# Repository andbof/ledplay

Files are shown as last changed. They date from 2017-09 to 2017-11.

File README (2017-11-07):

Ledplay is a small project aimed as a childrens toy. It uses a Cortex M0+
(Kinetis KE04, MKE04Z8VWJ4) to light button leds in binary order, waiting for
them to be pressed. When a complete number has been pressed, it progresses to
the next, until all have been exhausted. It then resets from one.

Copyright (C) 2016 Andreas Bofjäll <andreas@gazonk.org>, see LICENSE for
licensing details.

DESIGN RATIONALE

  Power efficiency was paramount, but I still wanted to retain programmability
  and flexibility for future use cases. The whole circuit is running at around
  130 uA when no leds are lit, giving it a runtime of about 1 to 1.5 years on
  two double AA batteries. There are no current limiting resistors for the leds
  and the led dc-dc drives them using constant voltage, but they won't be lit
  long enough for their resistance drop to become a problem.

  The led dc-dc is a SEPIC because originally, the leds would be driven with a
  lower voltage, but they turned out to be too dim.

SCHEMATICS AND PCB

  Schematic and PCB are made in Kicad. The PCB is a four layer board (mostly
  because I wanted to play with multilayer boards).

COMPILING

  Enter the src directory and run "make". You need a standard gcc arm toolchain
  (arm-none-eabi-*) installed, but nothing else. Ledplay does not use CMSIS.

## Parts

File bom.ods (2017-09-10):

 | Producer | Model | Note | Distributor | Art. no | Price (each) | Needed | Ordered | Sum | Buy | Board names
Battery holder | Keystone | 2463 |  | Farnell | 1702631 | 11.00 kr | 1 |  | 11.00 kr
Capacitor | Walsin | 1206X226K160CT | 22 uF, 16V, X5R, 1206 | Farnell | 2497154 | 3.08 kr | 3 |  | 9.24 kr |  | C1 C12 C17
Capacitor | TDK | C2012X7R1C105K125AA | 1 uF, 16V, X7R, 0805 | Farnell | 2346937 | 0.52 kr | 4 |  | 2.07 kr |  | C8 C10 C13 C16
Capacitor | TDK | C3216X7R1C106M160AC | 10 uF, 16V, X7R, 1206 | Farnell | 2309039 | 1.60 kr | 3 |  | 4.80 kr |  | C3 C18 C20
Capacitor | Kemet | C0603C180J5GACTU | 18 pF, C0G, 0603 | Farnell | 1414620 | 0.22 kr | 2 |  | 0.44 kr |  | C5 C6
Capacitor | Murata | GCM1885C1H221JA16D | 220 pF, C0G, 0603 | Farnell | 2494190 | 0.10 kr | 1 |  | 0.10 kr |  | C15
Capacitor | Multicomp | MC0603B104K250CT | 100 nF, X7R, 0603 | Farnell | 2310560 | 0.02 kr | 7 |  | 0.14 kr | No | C2 C4 C7 C9 C11 C14 C19
Connector | Molex | 22-23-2021 | 1x2, battery | Farnell | 1462926 | 0.74 kr | 1 |  | 0.74 kr |  | P1
Connector | TE / AMP | 281695-5 | 5 pins, keyed | Farnell | 1205986 | 2.95 kr | 4 |  | 11.80 kr |  | P2 P3 P4 P5
Connector | TE / AMP | 281838-5 | 5 pins, keyed | Farnell | 429600 | 1.75 kr | 4 |  | 7.00 kr
Connector | Wurth | 61900211621 | 1x2, battery | Farnell | 1841370 | 1.20 kr | 1 |  | 1.20 kr
CPU | NXP | MKE04Z8VWJ4 |  | Farnell | 2409293 | 8.77 kr | 1 |  | 8.77 kr |  | U1
Crystal | TXC | 9C-14.7456MEEJ-T | 14.7456 MHz | Farnell | 1842290 | 5.60 kr | 1 |  | 5.60 kr |  | Y1
DC/DC | Linear | LT1610 |  | Farnell | 2252763 | 39.53 kr | 1 |  | 39.53 kr |  | U4
DC/DC | Linear | LTC3429 |  | Farnell | 1663903 | 39.35 kr | 1 |  | 39.35 kr |  | U5
Header |  |  | 1x3, through hole |  |  |  | 1 |  | 0.00 kr | No | J1
Header |  |  | 1x2, through hole |  |  |  | 2 |  | 0.00 kr | No | JP1 P6
Header |  |  | 2x10, 1x27 mm, th | Farnell | 1022308 | 21.70 kr | 1 |  | 21.70 kr |  | J2
Inductance | Bourns | SRF0703-220M | Dual, 22 uH | Farnell | 1852820 | 8.65 kr | 1 |  | 8.65 kr |  | L1
Inductance | Murata | LQH43PN6R8M26L | 6.8 uH, 1812 | Farnell | 2219286 | 2.13 kr | 2 |  | 4.26 kr |  | L2
LED | Multicomp | 703-0087 | Green, 2.1 V, 572 nm | Farnell | 2112096 | 1.80 kr | 4 |  | 7.20 kr
Mosfet | NXP | NXP-BSS138BK |  | Farnell | 2053833 | 0.32 kr | 4 |  | 1.29 kr |  | Q1 Q2 Q3 Q4
Resistor | Panasonic | ERJ3RED2203V | 220 kohm, 0,5%, 0603 | Farnell | 2380163 | 0.59 kr | 1 |  | 0.59 kr |  | R28
Resistor | Vishay | CRCW0603604KFKEA | 604 kohm, 0603 | Farnell | 2138581 | 0.33 kr | 1 |  | 0.33 kr |  | R33
Resistor | Panasonic | ERJ3EKF7873V | 787 kohm, 0603 | Farnell | 2303313 | 0.10 kr | 1 |  | 0.10 kr |  | R30
Resistor | Panasonic | ERJ3RED5603V | 560 kohm, 0,5%, 0603 | Farnell | 2380240 | 0.59 kr | 1 |  | 0.59 kr |  | R29
Resistor | Panasonic | ERJ3RED1004V | 1 Mohm, 0.5%, 0603 | Farnell | 2380099 | 0.56 kr | 1 |  | 0.56 kr |  | R31
Resistor | Yageo | RC0603FR-07330RL | 330 ohm, 0603 | Farnell | 9238425 | 0.16 kr | 1 |  | 0.16 kr |  | R6
Resistor | Multicomp | MC0063W060311K | 1 kohm, 0603 | Farnell | 2130855 | 0.00 kr | 8 |  | 0.04 kr | No | R7 R8 R9 R10 R17 R18 R19 R20
Resistor | Multicomp | MC0063W0603110K | 10 kohm, 0603 | Farnell | 2130939 | 0.02 kr | 3 |  | 0.05 kr | No | R2 R3 R4
Resistor | Multicomp | MCMR06X2002FTL | 20 kohm, 0603 | Farnell | 2073421 | 0.09 kr | 1 |  | 0.09 kr |  | R32
Resistor | Multicomp | MCWR06X1003FTL | 100 kohm, 0603 | Farnell | 2447226RL | 0.01 kr | 12 |  | 0.16 kr | No | R11 R12 R13 R14 R15 R16 R21 R22 R23 R24 R25 R26
Schmitt NAND | TI | CD4093BM96 | Quad | Farnell | 2407129 | 1.78 kr | 2 |  | 3.56 kr |  | U2 U3
Schottky diode | ON | MBR0520LT3G |  | Farnell | 2533224 | 0.70 kr | 2 |  | 1.40 kr |  | D1 D2
Switch | C&K | KSEM31G LFS | 50 mA, SMD | Farnell | 2435310 | 2.55 kr | 1 |  | 2.55 kr |  | SW1
SUM |  |  |  |  |  |  | 85 | 0 | 195.05 kr

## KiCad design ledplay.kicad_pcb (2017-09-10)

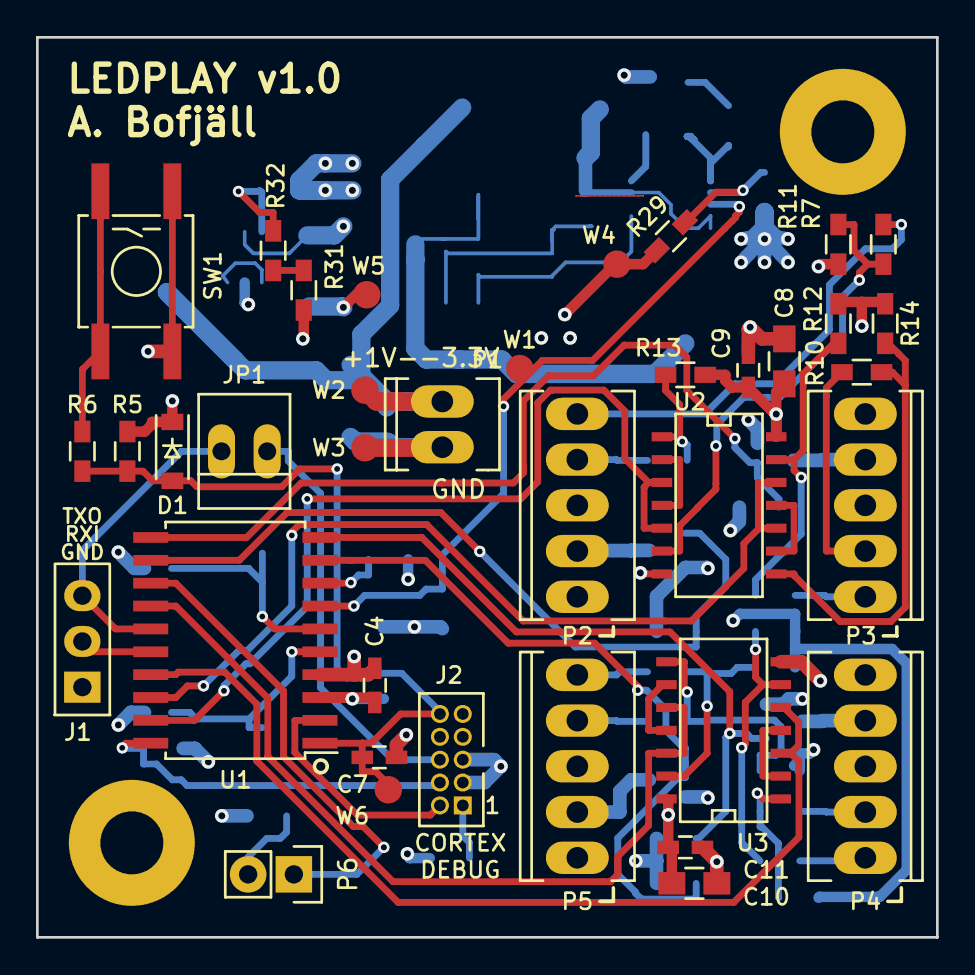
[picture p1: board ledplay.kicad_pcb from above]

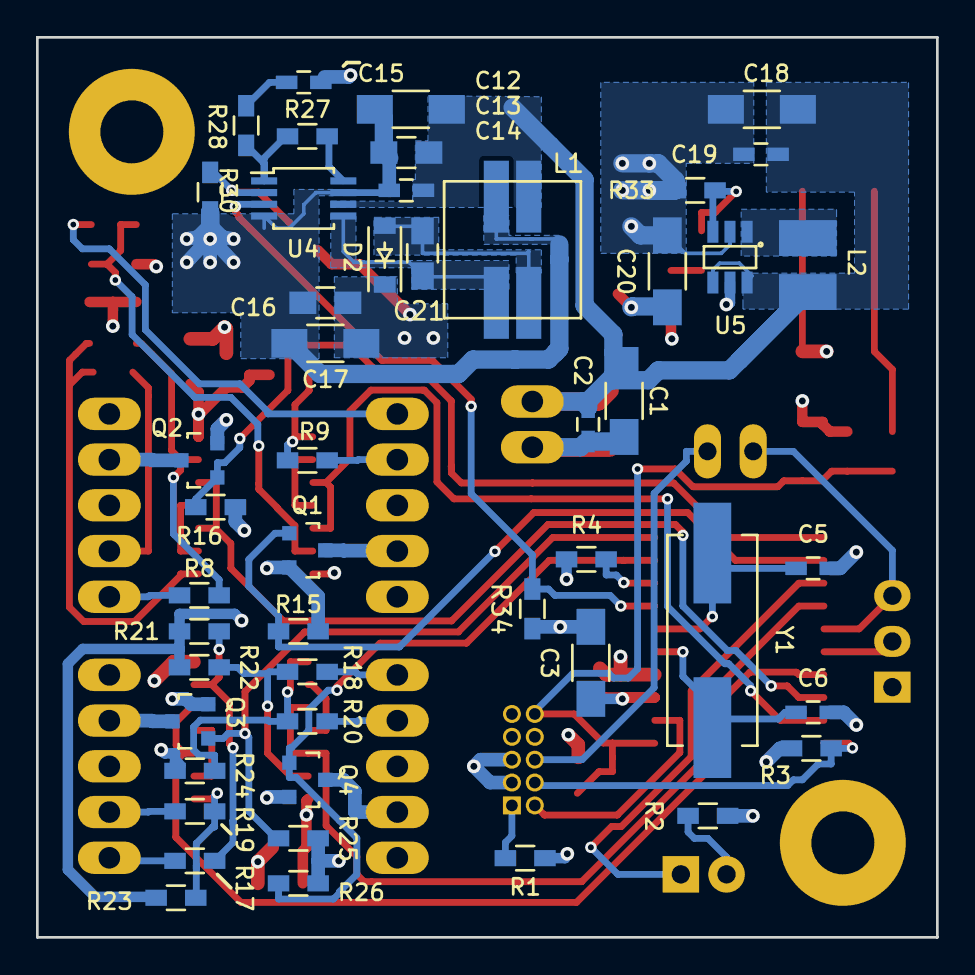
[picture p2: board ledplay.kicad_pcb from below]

Board: 4 copper layers, 50.0 x 50.0 mm, 87 parts (48 on the bottom side), 59 nets.

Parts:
C1, C12, C17: 22 uF; C_1206_HandSoldering
C2, C4, C7, C9, C11, C14, C19: 100 nF; C_0603_HandSoldering
C3, C18, C20: 10 uF; C_1206_HandSoldering
C5, C6: 18 pF; C_0603_HandSoldering
C8, C10, C13, C16, C21: 1 uF; C_0805_HandSoldering
C15: 220 pF; C_0603_HandSoldering
D1, D2: MBR0520LT3G; SOD-123
J1: UART_CONN
J2: CORTEX_DEBUG
JP1: JUMPER; PINHEAD1-2
L1: 22 uH; SRF0703
L2: 6.8 uH; INDUCTOR_1812
MP1, MP2: PLATED_HOLE
P1: PWRCON_01X02; Socket_MOLEX-KK-RM2-54mm_Lock_2pin_straight
P2, P3, P4, P5: CONN_01X05; Socket_MOLEX-KK-RM2-54mm_Lock_5pin_straight
P6: CONN_01X02; Pin_Header_Straight_1x02
Q1, Q2, Q3, Q4: BSS138; SOT-23
R1, R5, R27: NP; R_0603_HandSoldering
R2, R3, R4: 10k; R_0603_HandSoldering
R6: 330; R_0603_HandSoldering
R7, R8, R9, R10, R17, R18, R19, R20: 1k; R_0603_HandSoldering
R11, R12, R13, R14, R15, R16, R21, R22, R23, R24, R25, R26, R34: 100k; R_0603_HandSoldering
R28: 220k; R_0603_HandSoldering
R29: 560k; R_0603_HandSoldering
R30: 787k; R_0603_HandSoldering
R31: 1M; R_0603_HandSoldering
R32: 20k; R_0603_HandSoldering
R33: 604k; R_0603_HandSoldering
SW1: SW_PUSH; SW_KSEM31G
U1: MKE04Z8VWJ4; SOIC-20_7.5x12.8mm_Pitch1.27mm
U2, U3: 4093; SOIC-14_N
U4: LT1610; MSOP-8
U5: LTC3429; SOT-23
W1, W2, W3, W4, W5, W6: TEST_1P; Measurement_Point_Round-SMD-Pad_Small
Y1: 14.7456 MHz; Crystal_HC49-SD_SMD

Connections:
+3V3: C3.1, C4.1, C8.1, C9.1, C10.1, C11.1, C20.1, D1.1, R1.1, R4.1, R5.1, R11.1, R12.1, R13.1, R14.1, R21.1, R22.1, R23.1, R24.1, R31.1, U1.3, U2.14, U3.14, U5.5, W5.1
+BATT: C1.1, C2.1, C12.1, C13.1, C14.1, C18.1, C19.1, L1.3, L2.2, P1.2, U4.6, U5.4, U5.6, W2.1
+LED: C16.1, C17.1, D2.1, P2.1, P3.1, P4.1, P5.1, R29.1, W4.1
/AUX: P6.1, U1.13
/EXTAL: C6.1, U1.5, Y1.2
/LEDSWITCH_CTRL/GND_LED1: P2.2, Q1.3
/LEDSWITCH_CTRL/GND_LED2: P3.2, Q2.3
/LEDSWITCH_CTRL/GND_LED3: P4.2, Q3.3
/LEDSWITCH_CTRL/GND_LED4: P5.2, Q4.3
/LEDSWITCH_CTRL/LED1_CTRL: Q1.1, R15.1, U1.12
/LEDSWITCH_CTRL/LED2_CTRL: Q2.1, R16.1, U1.11
/LEDSWITCH_CTRL/LED3_CTRL: Q3.1, R25.1, U1.10
/LEDSWITCH_CTRL/LED4_CTRL: Q4.1, R26.1, U1.9
/LEDSWITCH_CTRL/SW1_STATE: U1.19, U2.3, U2.5
/LEDSWITCH_CTRL/SW2_STATE: U1.18, U2.10, U2.12
/LEDSWITCH_CTRL/SW3_STATE: U1.17, U3.3, U3.5
/LEDSWITCH_CTRL/SW4_STATE: U1.14, U3.10, U3.12
/LED_POWER/~LED_SHDN: R34.1, U1.7, U4.3, W1.1
/NMI: R4.2, U1.8
/SWCLK: J2.4, R3.1, U1.20
/SWDIO: J2.2, U1.2
/UART0_RX: J1.2, U1.16
/UART0_TX: J1.3, JP1.2, U1.15
/XTAL: C5.1, U1.6, Y1.1
/~MCU_RESET: C7.1, D1.2, J2.10, R5.2, R6.2, U1.1, W6.1
GND: C1.2, C2.2, C3.2, C4.2, C5.2, C6.2, C7.2, C8.2, C9.2, C10.2, C11.2, C12.2, C13.2, C14.2, C15.2, C16.2, C17.2, C18.2, C19.2, C20.2, J1.1, J2.3, J2.5, L1.4, MP1.1, MP2.1, P1.1, P2.3, P3.3, P4.3, P5.3, Q1.2, Q2.2, Q3.2, Q4.2, R2.2, R3.2, R15.2, R16.2, R25.2, R26.2, R30.2, R33.2, R34.2, SW1.2, U1.4, U2.7, U3.7, U4.4, U4.7, U5.2, W3.1
unnamed: C15.1, R28.2
unnamed: C21.1, L1.1, U4.5
unnamed: C21.2, D2.2, L1.2
unnamed: J2.1, R1.2
unnamed: J2.6, JP1.1
unnamed: L2.1, U5.1
unnamed: P2.4, R9.2
unnamed: P2.5, R7.2
unnamed: P3.4, R10.2
unnamed: P3.5, R8.2
unnamed: P4.4, R19.2
unnamed: P4.5, R17.2
unnamed: P5.4, R20.2
unnamed: P5.5, R18.2
unnamed: P6.2, R2.1
unnamed: R6.1, SW1.1
unnamed: R10.1, R14.2, U2.8
unnamed: R7.1, R11.2, U2.6
unnamed: R8.1, R12.2, U2.13
unnamed: R9.1, R13.2, U2.1
unnamed: R17.1, R21.2, U3.6
unnamed: R18.1, R22.2, U3.13
unnamed: R19.1, R23.2, U3.1
unnamed: R20.1, R24.2, U3.8
unnamed: R27.1, U4.8
unnamed: R27.2, R28.1, U4.1
unnamed: R29.2, R30.1, U4.2
unnamed: R31.2, R32.1
unnamed: R32.2, R33.1, U5.3
unnamed: U2.2, U2.4
unnamed: U2.9, U2.11
unnamed: U3.2, U3.4
unnamed: U3.9, U3.11

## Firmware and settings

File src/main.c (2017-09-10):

#include <stdint.h>
#include <stdlib.h>
#include <stdio.h>
#include <string.h>

#include "button.h"
#include "clock.h"
#include "gpio.h"
#include "interrupt.h"
#include "memorymap.h"
#include "sleep.h"
#include "uart.h"

static void print_reset_reason(void)
{
	uart0_send_str("Reset reason:\r\n");
	if (SIM_SRSID & SIM_SRSID_SACKERR)
		uart0_send_str("  Stop mode acknowledge error\r\n");
	if (SIM_SRSID & SIM_SRSID_MDMAP)
		uart0_send_str("  MDM-AP system reset request\r\n");
	if (SIM_SRSID & SIM_SRSID_SW)
		uart0_send_str("  Software request\r\n");
	if (SIM_SRSID & SIM_SRSID_LOCKUP)
		uart0_send_str("  Core lockup\r\n");
	if (SIM_SRSID & SIM_SRSID_POR)
		uart0_send_str("  Power-on reset\r\n");
	if (SIM_SRSID & SIM_SRSID_PIN)
		uart0_send_str("  External reset pin\r\n");
	if (SIM_SRSID & SIM_SRSID_WDOG)
		uart0_send_str("  Watchdog reset\r\n");
	if (SIM_SRSID & SIM_SRSID_LOC)
		uart0_send_str("  Internal clock source module reset\r\n");
	if (SIM_SRSID & SIM_SRSID_LVD)
		uart0_send_str("  Low voltage detect\r\n");
}

static void init_spmsc(void)
{
	/*
	 * Disable low voltage detection, savings measured at about 140 uA
	 */
	PMC_SPMSC1 = 0x00;
	PMC_SPMSC2 = 0x00;
}

int main(void)
{
	init_spmsc();
	init_pinmux();
	init_clock();
	init_uart();
	init_buttons();
	enable_interrupts();

	uart0_send_str("LEDPLAY v1.0\r\n");
	print_reset_reason();

	sleep_forever();

	return 0;
}

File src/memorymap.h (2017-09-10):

#include <stdint.h>

/* 12.2.1 System Reset Status and ID Register (SIM_SRSID) */
#define SIM_SRSID (*(volatile uint32_t*)(0x40048000))
#define SIM_SRSID_SACKERR (1 << 13)
#define SIM_SRSID_MDMAP (1 << 11)
#define SIM_SRSID_SW (1 << 10)
#define SIM_SRSID_LOCKUP (1 << 9)
#define SIM_SRSID_POR (1 << 7)
#define SIM_SRSID_PIN (1 << 6)
#define SIM_SRSID_WDOG (1 << 5)
#define SIM_SRSID_LOC (1 << 2)
#define SIM_SRSID_LVD (1 << 1)

/* 12.2.2 System Options Register (SIM_SOPT) */
#define SIM_SOPT (*(volatile uint32_t*)(0x40048004))
#define NMIE (1 << 1)

/* 12.2.3 Pin Selection Register (SIM_PINSEL) */
#define SIM_PINSEL (*(volatile uint32_t*)(0x40048008))
#define PWTCLKPS (1 << 31)
#define FTM2CLKPS (1 << 30)
#define FTM0CLKPS (1 << 28)
#define FTM2PS3 (1 << 15)
#define FTM2PS2 (1 << 14)
#define FTM0PS1 (1 << 9)
#define FTM0PS0 (1 << 8)
#define UART0PS (1 << 7)
#define SPI0PS (1 << 6)
#define I2C0PS (1 << 5)

/* 12.2.4 System Clock Gating Control Register (SIM_SCGC) */
#define SIM_SCGC (*(volatile uint32_t*)(0x4004800c))
#define ACMP1 (1 << 31)
#define ACMP0 (1 << 30)
#define ADC (1 << 29)
#define IRQ (1 << 27)
#define KBI1 (1 << 25)
#define KBI0 (1 << 24)
#define UART0 (1 << 20)
#define SPI0 (1 << 18)
#define I2C (1 << 17)
#define SWD (1 << 13)
#define FLASH (1 << 12)
#define CRC (1 << 10)
#define FTM2 (1 << 7)
#define FTM0 (1 << 5)
#define PWT (1 << 4)
#define PIT (1 << 1)
#define RTC (1 << 0)

/* 12.2.8 Clock Divider Register (SIM_CLKDIV) */
#define SIM_CLKDIV (*(volatile uint32_t*)(0x4004801c))

/* 13.4.1 System Power Management Status and Control 1 Register (PMC_SPMSC1) */
#define PMC_SPMSC1 (*(volatile uint8_t*)(0x4007d000))
#define PMC_SPMSC1_LVWF (1 << 7)
#define PMC_SPMSC1_LVWACK (1 << 6)
#define PMC_SPMSC1_LVWIE (1 << 5)
#define PMC_SPMSC1_LVDRE (1 << 4)
#define PMC_SPMSC1_LVDSE (1 << 3)
#define PMC_SPMSC1_LVDE (1 << 2)
#define PMC_SPMSC1_BGBE (1 << 0)

/* 13.4.2 System Power Management Status and Control 2 Register (PMC_SPMSC2) */
#define PMC_SPMSC2 (*(volatile uint8_t*)(0x4007d001))
#define PMC_SPMSC2_LVDV (1 << 6)
#define PMC_SPMSC2_LVWV_LOW (0)
#define PMC_SPMSC2_LVWV_MIDDLE1 (1 << 4)
#define PMC_SPMSC2_LVWV_MIDDLE2 (1 << 5)
#define PMC_SPMSC2_LVWV_HIGH (1 << 5 | 1 << 4)

/* 16.2.1 Watchdog Control and Status Register 1 (WDOG_CS1) */
#define WDOG_CS1 (*(volatile uint8_t*)(0x40052000))
#define WDOG_EN (1 << 7)
#define WDOG_INT (1 << 6)
#define WDOG_UPDATE (1 << 5)
#define WDOG_TST (1 << 4 | 1 << 3)
#define WDOG_DBG (1 << 2)
#define WDOG_WAIT (1 << 1)
#define WDOG_STOP (1 << 0)

/* 16.2.2 Watchdog Control and Status Register 2 (WDOG_CS2) */
#define WDOG_CS2 (*(volatile uint8_t*)(0x40052001))
#define WDOG_WIN (1 << 7)
#define WDOG_FLG (1 << 6)
#define WDOG_PRES (1 << 4)
#define WDOG_CLK (1 << 1 | 1 << 0)

/* 16.2.3 Watchdog Counter Register: High (WDOG_CNTH) */
#define WDOG_CNTH (*(volatile uint8_t*)(0x40052002))

/* 16.2.4 Watchdog Counter Register: Low (WDOG_CNTL) */
#define WDOG_CNTL (*(volatile uint8_t*)(0x40052003))

/*
 * According to the reference manual, this register is not defined for word
 * access, but the chapter on "Configuring watchdog" uses it that way and in
 * when testing it turned out byte access didn't properly disable the watchdog
 * (but word access did).
 */
#define WDOG_CNT (*(volatile uint16_t*)(0x40052002))

/* 16.2.5 Watchdog Timeout Value Register: High (WDOG_TOVALH) */
#define WDOG_TOVALH (*(volatile uint8_t*)(0x40052004))

/* 16.2.6 Watchdog Timeout Value Register: Low (WDOG_TOVALL) */
#define WDOG_TOVALL (*(volatile uint8_t*)(0x40052005))

/* 16.2.7 Watchdog Window Register: High (WDOG_WINH) */
#define WDOG_WINH (*(volatile uint8_t*)(0x40052006))

/* 16.2.8 Watchdog Window Register: Log (WDOG_WINL) */
#define WDOG_WINL (*(volatile uint8_t*)(0x40052007))

/* 32.2 UART signal descriptions */
#define UART0_BDH (*(volatile uint8_t*)(0x4006a000))
#define UART0_BDL (*(volatile uint8_t*)(0x4006a001))
#define UART0_C1 (*(volatile uint8_t*)(0x4006a002))
#define UART0_C2 (*(volatile uint8_t*)(0x4006a003))
#define UART0_S1 (*(volatile const uint8_t*)(0x4006a004))
#define UART0_S2 (*(volatile uint8_t*)(0x4006a005))
#define UART0_C3 (*(volatile uint8_t*)(0x4006a006))
#define UART0_D (*(volatile uint8_t*)(0x4006a007))

/* 32.3.1 UART Baud Rate Register: High (UARTx_BDH) */
#define LBKDIE (1 << 7)
#define RXEDGIE (1 << 6)
#define SBNS (1 << 5)
#define SBRH (1 << 3 | 1 << 2 | 1 << 1 | 1 << 0)

/* 32.3.3 UART Control Register 1 (UARTx_C1) */
#define LOOPS (1 << 7)
#define UARTSWAI (1 << 6)
#define RSRC (1 << 5)
#define C1_M (1 << 4)
#define WAKE (1 << 3)
#define ILT (1 << 2)
#define C1_PE (1 << 1)
#define C1_PT (1 << 0)

/* 32.3.4 UART Control Register 2 (UARTx_C2) */
#define UART_TIE (1 << 7)
#define TCIE (1 << 6)
#define RIE (1 << 5)
#define ILIE (1 << 4)
#define C2_TE (1 << 3)
#define C2_RE (1 << 2)
#define RWU (1 << 1)
#define SBK (1 << 0)

/* 32.3.5 UART Status Register 1 (UARTx_S1) */
#define TDRE (1 << 7)
#define S1_TC (1 << 6)
#define RDRF (1 << 5)
#define IDLE (1 << 4)
#define S1_OR (1 << 3)
#define S1_NF (1 << 2)
#define S1_FE (1 << 1)
#define S1_PE (1 << 0)

/* 32.3.6 UART Status Register 2 (UARTx_S2) */
#define LBKDIF (1 << 7)
#define RXEDGIF (1 << 6)
#define RXINV (1 << 4)
#define RWUID (1 << 3)
#define BRK13 (1 << 2)
#define LBKDE (1 << 1)
#define RAF (1 << 0)

/* 32.3.7 UART Control Register 3 (UARTx_C3) */
#define R8 (1 << 7)
#define T8 (1 << 6)
#define TXDIR (1 << 5)
#define TXINV (1 << 4)
#define ORIE (1 << 3)
#define NEIE (1 << 2)
#define FEIE (1 << 1)
#define PEIE (1 << 0)

/* 33.2.1 GPIO/FGPIO register bits assignment */
#define GPIOA_PDOR (*(volatile uint32_t*)(0x400ff000))
#define GPIOA_PSOR (*(volatile uint32_t*)(0x400ff004))
#define GPIOA_PCOR (*(volatile uint32_t*)(0x400ff008))
#define GPIOA_PTOR (*(volatile uint32_t*)(0x400ff00c))
#define GPIOA_PDIR (*(volatile uint32_t*)(0x400ff010))
#define GPIOA_PDDR (*(volatile uint32_t*)(0x400ff014))
#define GPIOA_PIDR (*(volatile uint32_t*)(0x400ff018))

#define PTD7 (1 << 31)
#define PTD6 (1 << 30)
#define PTD5 (1 << 29)
#define PTD4 (1 << 28)
#define PTD3 (1 << 27)
#define PTD2 (1 << 26)
#define PTD1 (1 << 25)
#define PTD0 (1 << 24)
#define PTC7 (1 << 23)
#define PTC6 (1 << 22)
#define PTC5 (1 << 21)
#define PTC4 (1 << 20)
#define PTC3 (1 << 19)
#define PTC2 (1 << 18)
#define PTC1 (1 << 17)
#define PTC0 (1 << 16)
#define PTB7 (1 << 15)
#define PTB6 (1 << 14)
#define PTB5 (1 << 13)
#define PTB4 (1 << 12)
#define PTB3 (1 << 11)
#define PTB2 (1 << 10)
#define PTB1 (1 << 9)
#define PTB0 (1 << 8)
#define PTA7 (1 << 7)
#define PTA6 (1 << 6)
#define PTA5 (1 << 5)
#define PTA4 (1 << 4)
#define PTA3 (1 << 3)
#define PTA2 (1 << 2)
#define PTA1 (1 << 1)
#define PTA0 (1 << 0)
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

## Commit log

2017-09-10 Add layout and schematic
    [3v3_power.sch, bom.ods, led_power.sch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]
2017-09-10 Fix layout and schema (as sent for production)
    This matches hardware revision v1.0 sent for production.
    [bom.ods, ledplay.kicad_pcb]
2017-09-10 Fix power connector polarity
    The power connector had the wrong polarity in the schematic. Fix it to
    avoid confusion.
    [3v3_power.sch, led_power.sch, ledplay.kicad_pcb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]
2017-09-10 Fix erratas in layout and schematic
    For v1.1, a fix a few erratas found in the layout and schematic:
    - The CPU actively pulls the reset pin low when it goes into
    reset. This does not work with the reset circuitry in v1.0.
    Add D3 to fix this.
    - Update DC-DC resistor values to match led drive voltage.
    - Fix footprints.
    [3v3_power.sch, led_power.sch, ledplay.sch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]
